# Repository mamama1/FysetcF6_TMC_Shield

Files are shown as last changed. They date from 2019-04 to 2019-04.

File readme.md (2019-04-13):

This shield has been inspired from the great SilentStepStick Protector boards by Watterott.
Source, see https://github.com/watterott/SilentStepStick

Some silkscreen has been stripped but besides that, Watterott's design has been used completely unchanged regarding the protection diode circuitry.

This board allows you to apply up to 42V (max. recommended) or up to 50V (absolute maximum, not recommended) to your motors by not connecting the VM pin to the F6 mainboard.

This repository has been released under the Creative Commons Attribution Share-Alike License: https://creativecommons.org/licenses/by-sa/4.0/

The original repository owned by Watterott, containing the SilentStepStick and Protector source files was released under the same license, see here: https://github.com/watterott/SilentStepStick/blob/master/README.md

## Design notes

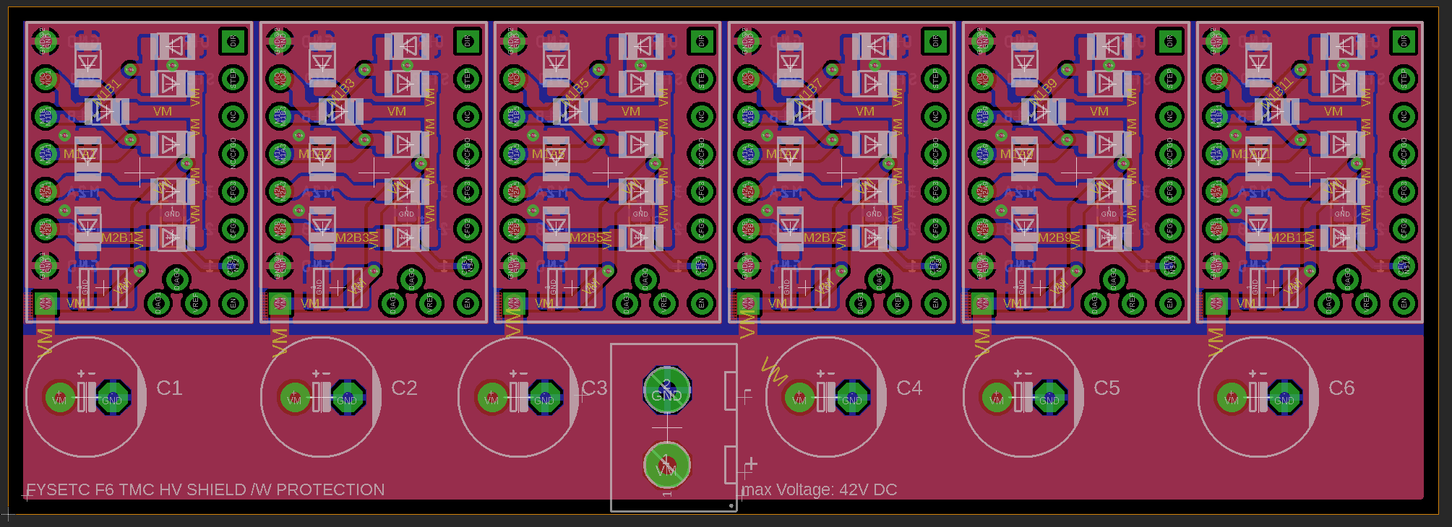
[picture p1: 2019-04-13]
preview.PNG

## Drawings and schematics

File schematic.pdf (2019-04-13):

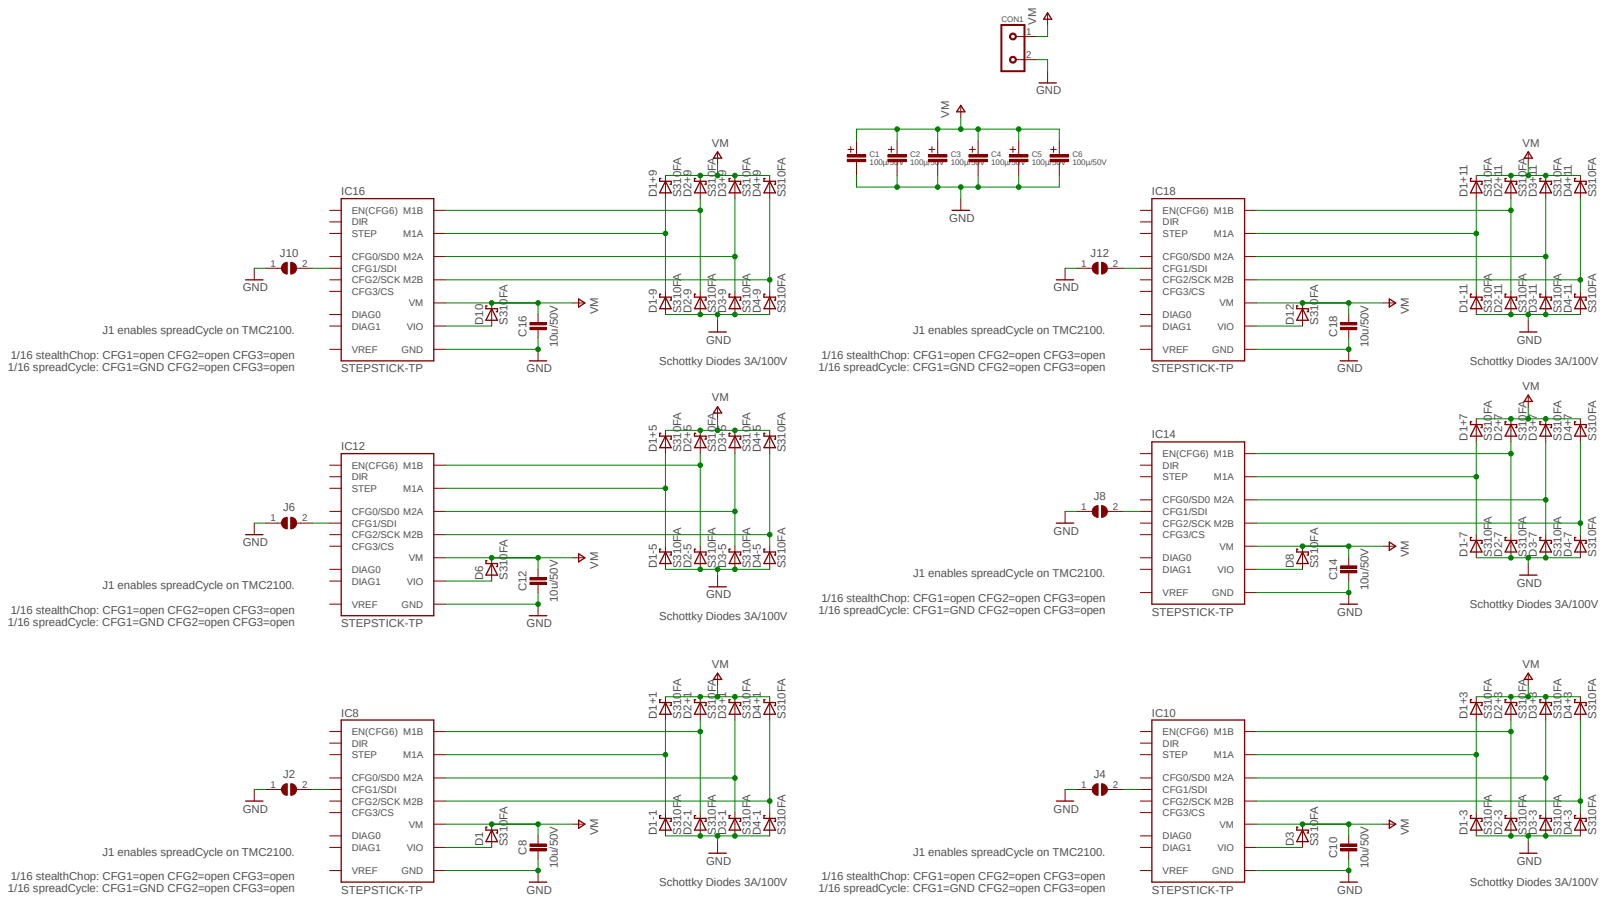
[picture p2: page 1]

1/16 stealthChop: CFG1=open CFG2=open CFG3=open

1/16 spreadCycle: CFG1=GND CFG2=open CFG3=open

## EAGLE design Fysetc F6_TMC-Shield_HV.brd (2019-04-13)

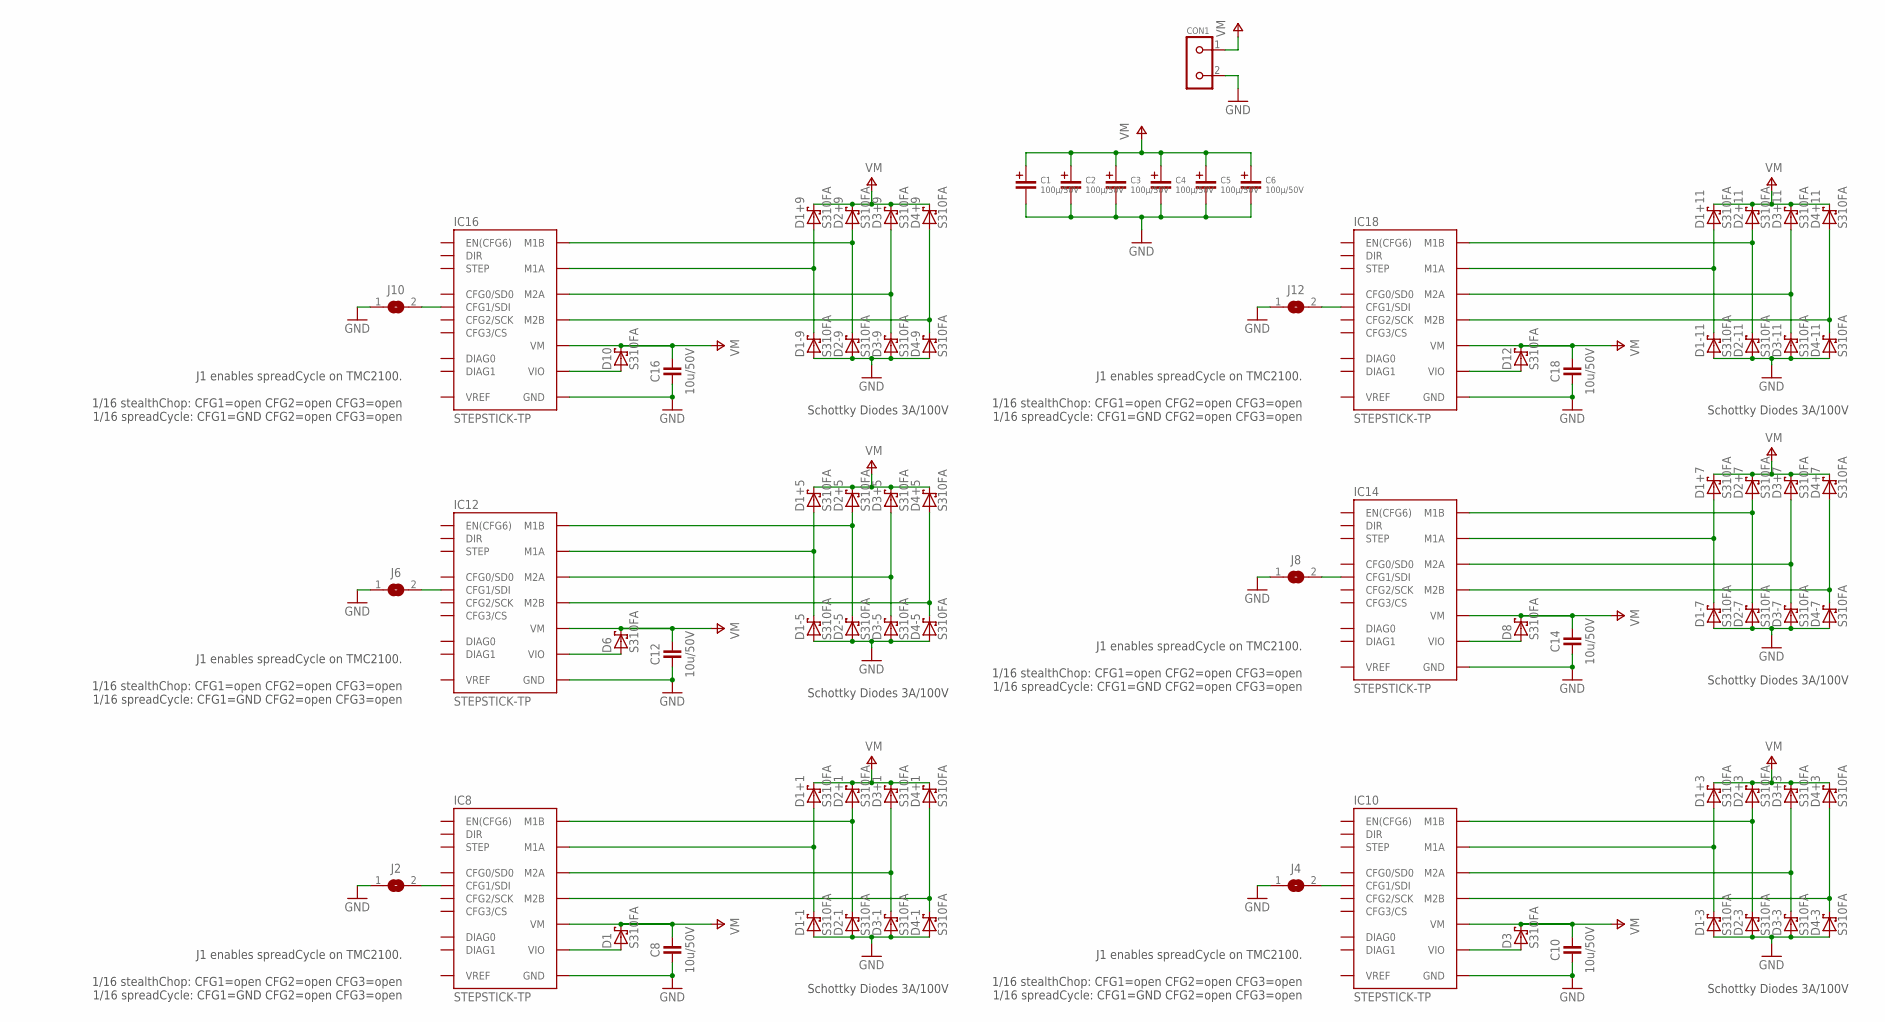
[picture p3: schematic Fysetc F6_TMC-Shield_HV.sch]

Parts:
C1, C2, C3, C4, C5, C6: 100µ/50V; C+/3.5/8
C8, C10, C12, C14, C16, C18: 10u/50V; C1210
CON1: KL2691311500002; KL2-691311500002
D1, D1+1, D1+3, D1+5, D1+7, D1+9, D1+11, D1-1, D1-3, D1-5, D1-7, D1-9, D1-11, D2+1, D2+3, D2+5, D2+7, D2+9, D2+11, D2-1, D2-3, D2-5, D2-7, D2-9, D2-11, D3, D3+1, D3+3, D3+5, D3+7, D3+9, D3+11, D3-1, D3-3, D3-5, D3-7, D3-9, D3-11, D4+1, D4+3, D4+5, D4+7, D4+9, D4+11, D4-1, D4-3, D4-5, D4-7, D4-9, D4-11, D6, D8, D10, D12: S310FA; SOD123
IC8, IC10, IC12, IC14, IC16, IC18: STEPSTICK-TP; STEPSTICK_TP
J2, J4, J6, J8, J10, J12: JUMPER2-0603-NC; JUMPER2-0603_NC

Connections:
GND: C1.-, C2.-, C3.-, C4.-, C5.-, C6.-, C8.1, C10.1, C12.1, C14.1, C16.1, C18.1, CON1.2, D1-1.A, D1-3.A, D1-5.A, D1-7.A, D1-9.A, D1-11.A, D2-1.A, D2-3.A, D2-5.A, D2-7.A, D2-9.A, D2-11.A, D3-1.A, D3-3.A, D3-5.A, D3-7.A, D3-9.A, D3-11.A, D4-1.A, D4-3.A, D4-5.A, D4-7.A, D4-9.A, D4-11.A, IC8.GND@1 (GND), IC8.GND@2 (GND), IC10.GND@1 (GND), IC10.GND@2 (GND), IC12.GND@1 (GND), IC12.GND@2 (GND), IC14.GND@1 (GND), IC14.GND@2 (GND), IC16.GND@1 (GND), IC16.GND@2 (GND), IC18.GND@1 (GND), IC18.GND@2 (GND), J2.1, J4.1, J6.1, J8.1, J10.1, J12.1
M1A1: D1+1.A, D1-1.C, IC8.M1A
M1A3: D1+3.A, D1-3.C, IC10.M1A
M1A5: D1+5.A, D1-5.C, IC12.M1A
M1A7: D1+7.A, D1-7.C, IC14.M1A
M1A9: D1+9.A, D1-9.C, IC16.M1A
M1A11: D1+11.A, D1-11.C, IC18.M1A
M1B1: D2+1.A, D2-1.C, IC8.M1B
M1B3: D2+3.A, D2-3.C, IC10.M1B
M1B5: D2+5.A, D2-5.C, IC12.M1B
M1B7: D2+7.A, D2-7.C, IC14.M1B
M1B9: D2+9.A, D2-9.C, IC16.M1B
M1B11: D2+11.A, D2-11.C, IC18.M1B
M2A1: D3+1.A, D3-1.C, IC8.M2A
M2A3: D3+3.A, D3-3.C, IC10.M2A
M2A5: D3+5.A, D3-5.C, IC12.M2A
M2A7: D3+7.A, D3-7.C, IC14.M2A
M2A9: D3+9.A, D3-9.C, IC16.M2A
M2A11: D3+11.A, D3-11.C, IC18.M2A
M2B1: D4+1.A, D4-1.C, IC8.M2B
M2B3: D4+3.A, D4-3.C, IC10.M2B
M2B5: D4+5.A, D4-5.C, IC12.M2B
M2B7: D4+7.A, D4-7.C, IC14.M2B
M2B9: D4+9.A, D4-9.C, IC16.M2B
M2B11: D4+11.A, D4-11.C, IC18.M2B
unnamed: IC8.CFG1 (CFG1/SDI), J2.2
unnamed: IC10.CFG1 (CFG1/SDI), J4.2
unnamed: IC12.CFG1 (CFG1/SDI), J6.2
unnamed: IC14.CFG1 (CFG1/SDI), J8.2
unnamed: IC16.CFG1 (CFG1/SDI), J10.2
unnamed: IC18.CFG1 (CFG1/SDI), J12.2
VIO1: D1.A, IC8.VIO
VIO3: D3.A, IC10.VIO
VIO5: D6.A, IC12.VIO
VIO7: D8.A, IC14.VIO
VIO9: D10.A, IC16.VIO
VIO11: D12.A, IC18.VIO
VM: C1.+, C2.+, C3.+, C4.+, C5.+, C6.+, C8.2, C10.2, C12.2, C14.2, C16.2, C18.2, CON1.1, D1.C, D1+1.C, D1+3.C, D1+5.C, D1+7.C, D1+9.C, D1+11.C, D2+1.C, D2+3.C, D2+5.C, D2+7.C, D2+9.C, D2+11.C, D3.C, D3+1.C, D3+3.C, D3+5.C, D3+7.C, D3+9.C, D3+11.C, D4+1.C, D4+3.C, D4+5.C, D4+7.C, D4+9.C, D4+11.C, D6.C, D8.C, D10.C, D12.C, IC8.VM, IC10.VM, IC12.VM, IC14.VM, IC16.VM, IC18.VM

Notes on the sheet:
Schottky Diodes 3A/100V
J1 enables spreadCycle on TMC2100. 1/16 stealthChop: CFG1=open CFG2=open CFG3=open 1/16 spreadCycle: CFG1=GND CFG2=open CFG3=open

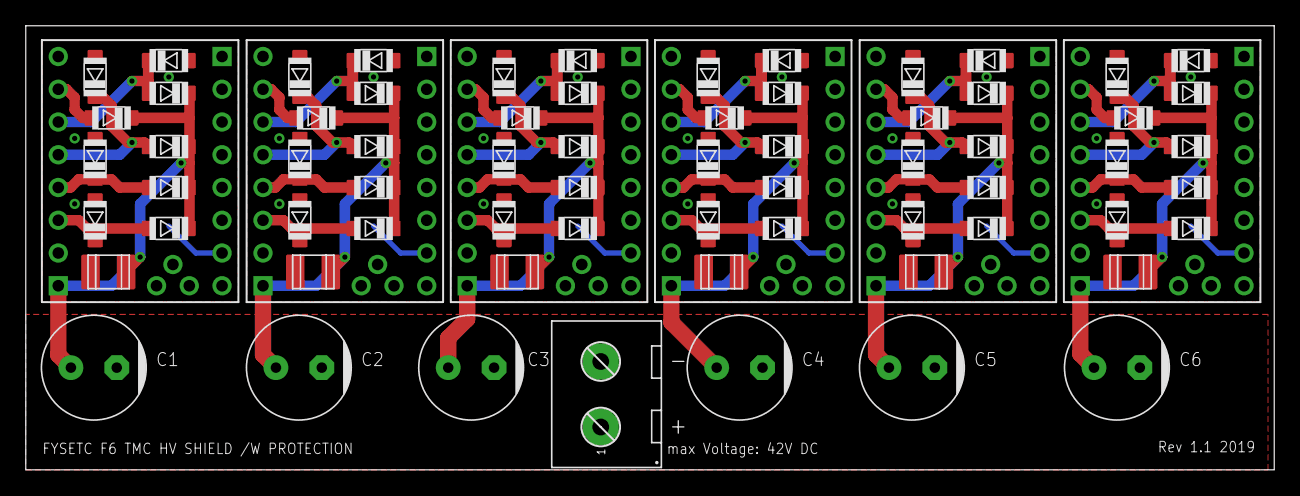
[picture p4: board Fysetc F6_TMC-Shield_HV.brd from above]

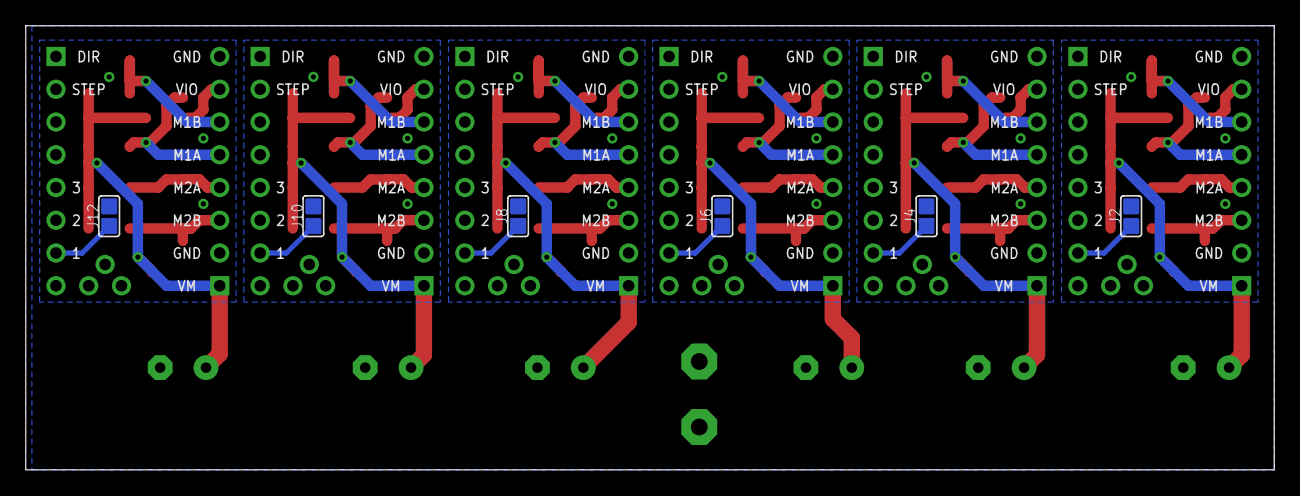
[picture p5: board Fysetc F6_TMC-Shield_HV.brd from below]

Board: 2 copper layers, 96.8 x 34.4 mm, 79 parts (6 on the bottom side), 38 nets.
